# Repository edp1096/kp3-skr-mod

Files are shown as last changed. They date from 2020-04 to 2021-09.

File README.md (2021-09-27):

# Working set for using SKR mini e3 board on Kingroon KP3
## WIP

## Folders
* Marlin_SKR_E3_v12_KP3 : Marlin for SKR Board
* Mount : STL, FreeCAD files
    * board_spacer - SKR board mount on KP3
    * board_spacer2 - Turned place of skr board 90 degree clock wise
        * Should remove 1 of stock mounting screw on floor of kp3 which hit skr board
    * display - Display mount for `tinyboy 12864 OLED Display`

## Marlin bugfix 2.0.x
* Marlin code from BIQU github and I fix a bug which not working save.

## Mount
* I used freecad for design board mount.
* Not tested yet. You may should check and edit dimension.

## Parts you should prepare
* USB mini-b cable
* JST XH2.5 Connector - `3pin (Stock MKS board)` to `2pin (SKR)` for fans connection on KP3
    * Crimp tool - https://www.amazon.com/IWISS-Terminal-Crimping-SN-01BM-0-08-0-5mm/dp/B019ARWWFY
    * Terminal - https://aliexpress.com/item/4000029855783.html
    * Connector - https://aliexpress.com/item/32715864245.html

* Display - <del>OLED 0.96`, Rotary Switch, Speaker</del>
    * ~~Zonestar OLED Display - https://aliexpress.com/item/4000839370779.html~~ - Not work

* ~~Micro sd extension adapter~~ - Because this give damage to sd card slot in SKR board so, do not use it.

## Todo
* [ ] <del>Schematic, Pin map for display</del>
* [x] Mount model for display
* [ ] Upload 12864 display schematic & pcb

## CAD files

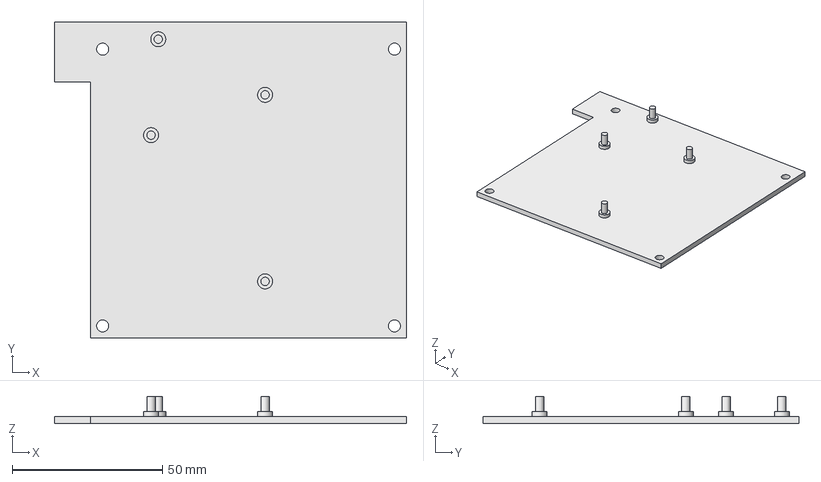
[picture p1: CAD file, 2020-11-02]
Mount/board_spacer2.FCStd
117.0 x 105.0 x 9.00 mm

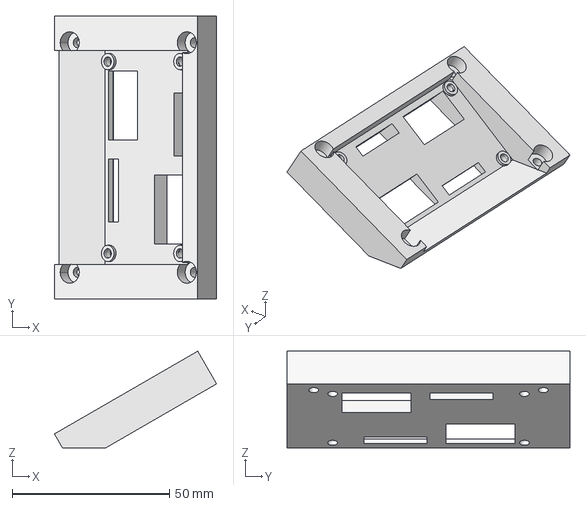
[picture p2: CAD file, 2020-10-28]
Mount/display.FCStd
51.6 x 90.0 x 30.7 mm

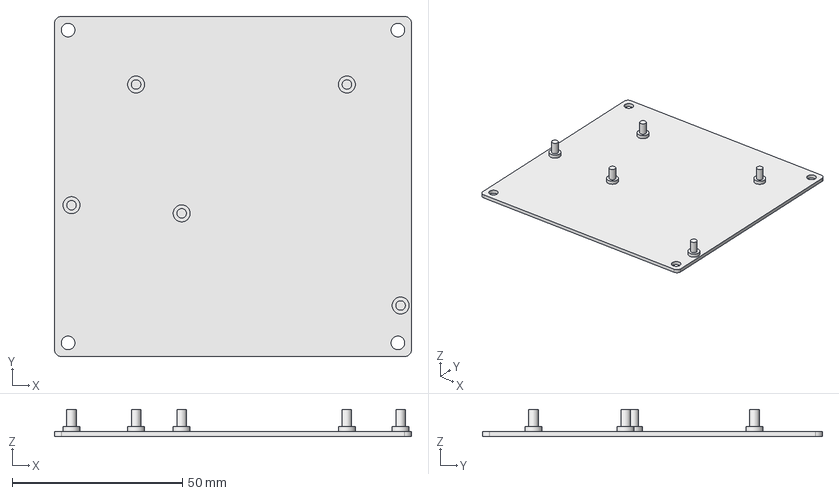
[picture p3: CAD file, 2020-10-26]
Mount/board_spacer.FCStd
105.0 x 100.0 x 8.00 mm

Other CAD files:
Mount/board_spacer.stl
Mount/board_spacer2.stl
Mount/display.stl

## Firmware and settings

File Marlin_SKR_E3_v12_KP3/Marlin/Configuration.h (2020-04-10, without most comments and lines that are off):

#pragma once
#define CONFIGURATION_H_VERSION 020000
#define STRING_CONFIG_H_AUTHOR "(BIGTREETECH, SKR-mini-E3)" // Who made the changes.
#define SHOW_BOOTSCREEN
#define SERIAL_PORT 2
#define SERIAL_PORT_2 -1
#define BAUDRATE 250000
  #define MOTHERBOARD BOARD_BTT_SKR_MINI_E3_V1_2
#define CUSTOM_MACHINE_NAME "SKR-mini-E3-V1.2"
#define EXTRUDERS 1
#define DEFAULT_NOMINAL_FILAMENT_DIA 1.75
#define TEMP_SENSOR_0 1
#define TEMP_SENSOR_1 0
#define TEMP_SENSOR_2 0
#define TEMP_SENSOR_3 0
#define TEMP_SENSOR_4 0
#define TEMP_SENSOR_5 0
#define TEMP_SENSOR_BED 1
#define TEMP_SENSOR_CHAMBER 0
#define DUMMY_THERMISTOR_998_VALUE 25
#define DUMMY_THERMISTOR_999_VALUE 100
#define MAX_REDUNDANT_TEMP_SENSOR_DIFF 10
#define TEMP_RESIDENCY_TIME     10  // (seconds) Time to wait for hotend to "settle" in M109
#define TEMP_WINDOW              1  // (°C) Temperature proximity for the "temperature reached" timer
#define TEMP_HYSTERESIS          3  // (°C) Temperature proximity considered "close enough" to the target
#define TEMP_BED_RESIDENCY_TIME 10  // (seconds) Time to wait for bed to "settle" in M190
#define TEMP_BED_WINDOW          1  // (°C) Temperature proximity for the "temperature reached" timer
#define TEMP_BED_HYSTERESIS      3  // (°C) Temperature proximity considered "close enough" to the target
#define HEATER_0_MINTEMP   5
#define HEATER_1_MINTEMP   5
#define HEATER_2_MINTEMP   5
#define HEATER_3_MINTEMP   5
#define HEATER_4_MINTEMP   5
#define HEATER_5_MINTEMP   5
#define BED_MINTEMP        5
#define HEATER_0_MAXTEMP 275
#define HEATER_1_MAXTEMP 275
#define HEATER_2_MAXTEMP 275
#define HEATER_3_MAXTEMP 275
#define HEATER_4_MAXTEMP 275
#define HEATER_5_MAXTEMP 275
#define BED_MAXTEMP      125
#define PIDTEMP
#define BANG_MAX 255     // Limits current to nozzle while in bang-bang mode; 255=full current
#define PID_MAX BANG_MAX // Limits current to nozzle while PID is active (see PID_FUNCTIONAL_RANGE below); 255=full current
#define PID_K1 0.95      // Smoothing factor within any PID loop
  #define PID_EDIT_MENU           // Add PID editing to the "Advanced Settings" menu. (~700 bytes of PROGMEM)
  #define PID_AUTOTUNE_MENU       // Add PID auto-tuning to the "Advanced Settings" menu. (~250 bytes of PROGMEM)
  #define PID_FUNCTIONAL_RANGE 10 // If the temperature difference between the target temperature and the actual temperature
  #define DEFAULT_Kp 21.73
  #define DEFAULT_Ki 1.54
  #define DEFAULT_Kd 76.55
#define MAX_BED_POWER 255 // limits duty cycle to bed; 255=full current
#define PREVENT_COLD_EXTRUSION
#define EXTRUDE_MINTEMP 170
#define PREVENT_LENGTHY_EXTRUDE
#define EXTRUDE_MAXLENGTH 200
#define THERMAL_PROTECTION_HOTENDS // Enable thermal protection for all extruders
#define THERMAL_PROTECTION_BED     // Enable thermal protection for the heated bed
#define THERMAL_PROTECTION_CHAMBER // Enable thermal protection for the heated chamber
#define USE_XMIN_PLUG
#define USE_YMIN_PLUG
#define USE_ZMIN_PLUG
#define ENDSTOPPULLUPS
#define X_MIN_ENDSTOP_INVERTING true // Set to true to invert the logic of the endstop.
#define Y_MIN_ENDSTOP_INVERTING true // Set to true to invert the logic of the endstop.
#define Z_MIN_ENDSTOP_INVERTING false // Set to true to invert the logic of the endstop.
#define X_MAX_ENDSTOP_INVERTING false // Set to true to invert the logic of the endstop.
#define Y_MAX_ENDSTOP_INVERTING false // Set to true to invert the logic of the endstop.
#define Z_MAX_ENDSTOP_INVERTING false // Set to true to invert the logic of the endstop.
#define Z_MIN_PROBE_ENDSTOP_INVERTING false // Set to true to invert the logic of the probe.
#define X_DRIVER_TYPE  TMC2209
#define Y_DRIVER_TYPE  TMC2209
#define Z_DRIVER_TYPE  TMC2209
#define E0_DRIVER_TYPE TMC2209
#define ENDSTOP_INTERRUPTS_FEATURE
#define DEFAULT_AXIS_STEPS_PER_UNIT   { 80, 80, 400, 93 }
#define DEFAULT_MAX_FEEDRATE          { 500, 500, 5, 25 }
#define DEFAULT_MAX_ACCELERATION      { 500, 500, 100, 5000 }
#define DEFAULT_ACCELERATION          500    // X, Y, Z and E acceleration for printing moves
#define DEFAULT_RETRACT_ACCELERATION  500    // E acceleration for retracts
#define DEFAULT_TRAVEL_ACCELERATION   500    // X, Y, Z acceleration for travel (non printing) moves
#define DEFAULT_EJERK    5.0  // May be used by Linear Advance
  #define JUNCTION_DEVIATION_MM 0.08  // (mm) Distance from real junction edge
#define Z_MIN_PROBE_USES_Z_MIN_ENDSTOP_PIN
#define BLTOUCH
#define NOZZLE_TO_PROBE_OFFSET { -43, -6, 0 }
#define MIN_PROBE_EDGE 10
#define XY_PROBE_SPEED 8000
#define Z_PROBE_SPEED_FAST HOMING_FEEDRATE_Z
#define Z_PROBE_SPEED_SLOW (Z_PROBE_SPEED_FAST / 2)
#define Z_CLEARANCE_DEPLOY_PROBE   10 // Z Clearance for Deploy/Stow
#define Z_CLEARANCE_BETWEEN_PROBES  5 // Z Clearance between probe points
#define Z_CLEARANCE_MULTI_PROBE     5 // Z Clearance between multiple probes
#define Z_PROBE_LOW_POINT          -2 // Farthest distance below the trigger-point to go before stopping
#define Z_PROBE_OFFSET_RANGE_MIN -20
#define Z_PROBE_OFFSET_RANGE_MAX 20
#define Z_MIN_PROBE_REPEATABILITY_TEST
#define X_ENABLE_ON 0
#define Y_ENABLE_ON 0
#define Z_ENABLE_ON 0
#define E_ENABLE_ON 0 // For all extruders
#define DISABLE_X false
#define DISABLE_Y false
#define DISABLE_Z false
#define DISABLE_E false             // For all extruders
#define INVERT_X_DIR true
#define INVERT_Y_DIR true
#define INVERT_Z_DIR false
#define INVERT_E0_DIR true
#define INVERT_E1_DIR false
#define INVERT_E2_DIR false
#define INVERT_E3_DIR false
#define INVERT_E4_DIR false
#define INVERT_E5_DIR false
#define X_HOME_DIR -1
#define Y_HOME_DIR -1
#define Z_HOME_DIR -1
#define X_BED_SIZE 180
#define Y_BED_SIZE 180
#define X_MIN_POS 0
#define Y_MIN_POS 0
#define Z_MIN_POS 0
#define X_MAX_POS X_BED_SIZE
#define Y_MAX_POS Y_BED_SIZE
#define Z_MAX_POS 180
#define MIN_SOFTWARE_ENDSTOPS
  #define MIN_SOFTWARE_ENDSTOP_X
  #define MIN_SOFTWARE_ENDSTOP_Y
  #define MIN_SOFTWARE_ENDSTOP_Z
#define MAX_SOFTWARE_ENDSTOPS
  #define MAX_SOFTWARE_ENDSTOP_X
  #define MAX_SOFTWARE_ENDSTOP_Y
  #define MAX_SOFTWARE_ENDSTOP_Z
#define AUTO_BED_LEVELING_BILINEAR
#define RESTORE_LEVELING_AFTER_G28
  #define ENABLE_LEVELING_FADE_HEIGHT
  #define SEGMENT_LEVELED_MOVES
  #define LEVELED_SEGMENT_LENGTH 5.0 // (mm) Length of all segments (except the last one)
  #define GRID_MAX_POINTS_X 7
  #define GRID_MAX_POINTS_Y GRID_MAX_POINTS_X
#define Z_SAFE_HOMING
  #define Z_SAFE_HOMING_X_POINT ((X_BED_SIZE) / 2)    // X point for Z homing when homing all axes (G28).
  #define Z_SAFE_HOMING_Y_POINT ((Y_BED_SIZE) / 2)    // Y point for Z homing when homing all axes (G28).
#define HOMING_FEEDRATE_XY (20*60)
#define HOMING_FEEDRATE_Z  (4*60)
#define VALIDATE_HOMING_ENDSTOPS
#define EEPROM_SETTINGS       // Persistent storage with M500 and M501
#define EEPROM_CHITCHAT       // Give feedback on EEPROM commands. Disable to save PROGMEM.
#define HOST_KEEPALIVE_FEATURE        // Disable this if your host doesn't like keepalive messages
#define DEFAULT_KEEPALIVE_INTERVAL 2  // Number of seconds between "busy" messages. Set with M113.
#define BUSY_WHILE_HEATING            // Some hosts require "busy" messages even during heating
#define PREHEAT_1_LABEL       "PLA"
#define PREHEAT_1_TEMP_HOTEND 185
#define PREHEAT_1_TEMP_BED     45
#define PREHEAT_1_FAN_SPEED   255 // Value from 0 to 255
#define PREHEAT_2_LABEL       "ABS"
#define PREHEAT_2_TEMP_HOTEND 240
#define PREHEAT_2_TEMP_BED      0
#define PREHEAT_2_FAN_SPEED   255 // Value from 0 to 255
#define PRINTJOB_TIMER_AUTOSTART
#define LCD_LANGUAGE en
#define DISPLAY_CHARSET_HD44780 WESTERN
#define LCD_INFO_SCREEN_STYLE 0
#define SDSUPPORT
#define U8GLIB_SSD1306
#define OLED_PANEL_TINYBOY2
#define FAN_SOFT_PWM
#define SOFT_PWM_SCALE 0
#define SERVO_DELAY { 300 }

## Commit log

2020-10-26 Add mount for zonestar display, modified mount for skr
    [board_spacer.FCStd, board_spacer.stl, display.FCStd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]
2020-10-26 Correct hole size and location
    [display.FCStd, display.stl]
2020-10-26 Re-upload broken display.stl
    [display.stl]
2020-10-26 Decrease hole height which oled board on
    [display.FCStd, display.stl]
2020-10-28 Add a another board_spacer, modified display
    [board_spacer2.FCStd, display.FCStd, display.stl]
2020-11-02 Edit floor on boardspacer2
    [board_spacer2.FCStd, board_spacer2.stl]

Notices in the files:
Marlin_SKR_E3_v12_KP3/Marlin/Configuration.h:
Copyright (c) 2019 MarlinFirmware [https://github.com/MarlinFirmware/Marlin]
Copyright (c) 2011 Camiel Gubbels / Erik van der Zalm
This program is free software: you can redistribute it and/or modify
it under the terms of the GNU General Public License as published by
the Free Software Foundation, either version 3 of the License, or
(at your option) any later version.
